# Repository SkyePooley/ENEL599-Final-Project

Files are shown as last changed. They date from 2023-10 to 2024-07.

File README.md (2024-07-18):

# Pong Game on Arduino LED Matrix
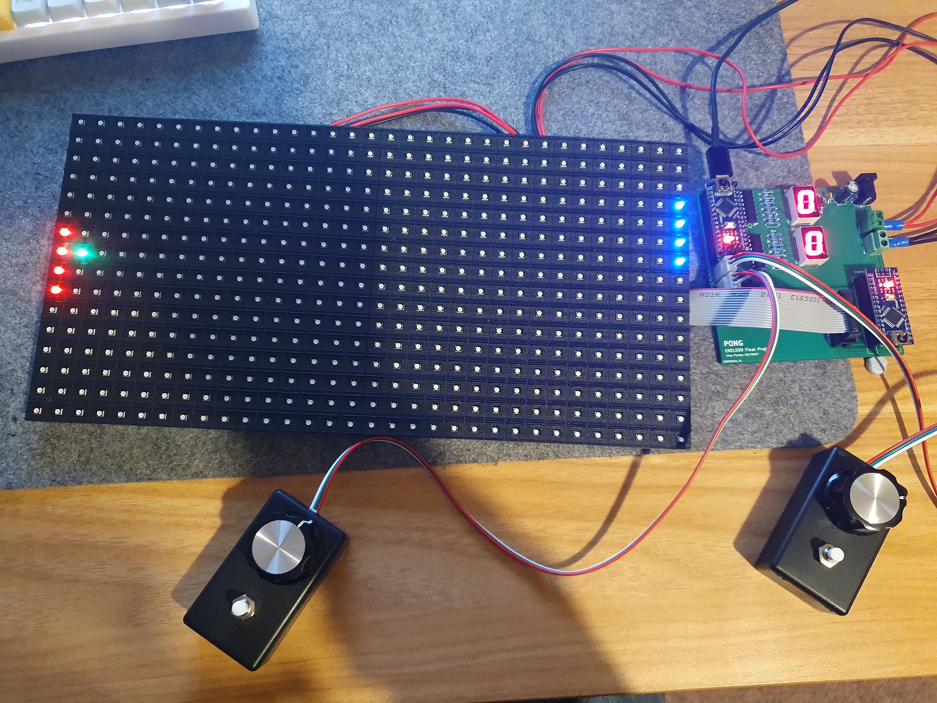
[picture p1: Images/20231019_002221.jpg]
Pong running on the game system

Recreation of Atari's *home pong* game system which plays a game of pong on a 64x32 LED matrix.  
This repository includes my schematics, PDB designs, and C++ code for the microcontrollers.
The PCB is designed for manufacturing with JLCPCB in two layers, exported files are included.

Schematic for mainboard

Due to memory constraints the functions of the system are split between two microcontrollers, one of which runs the game and IO while the other drives the display.

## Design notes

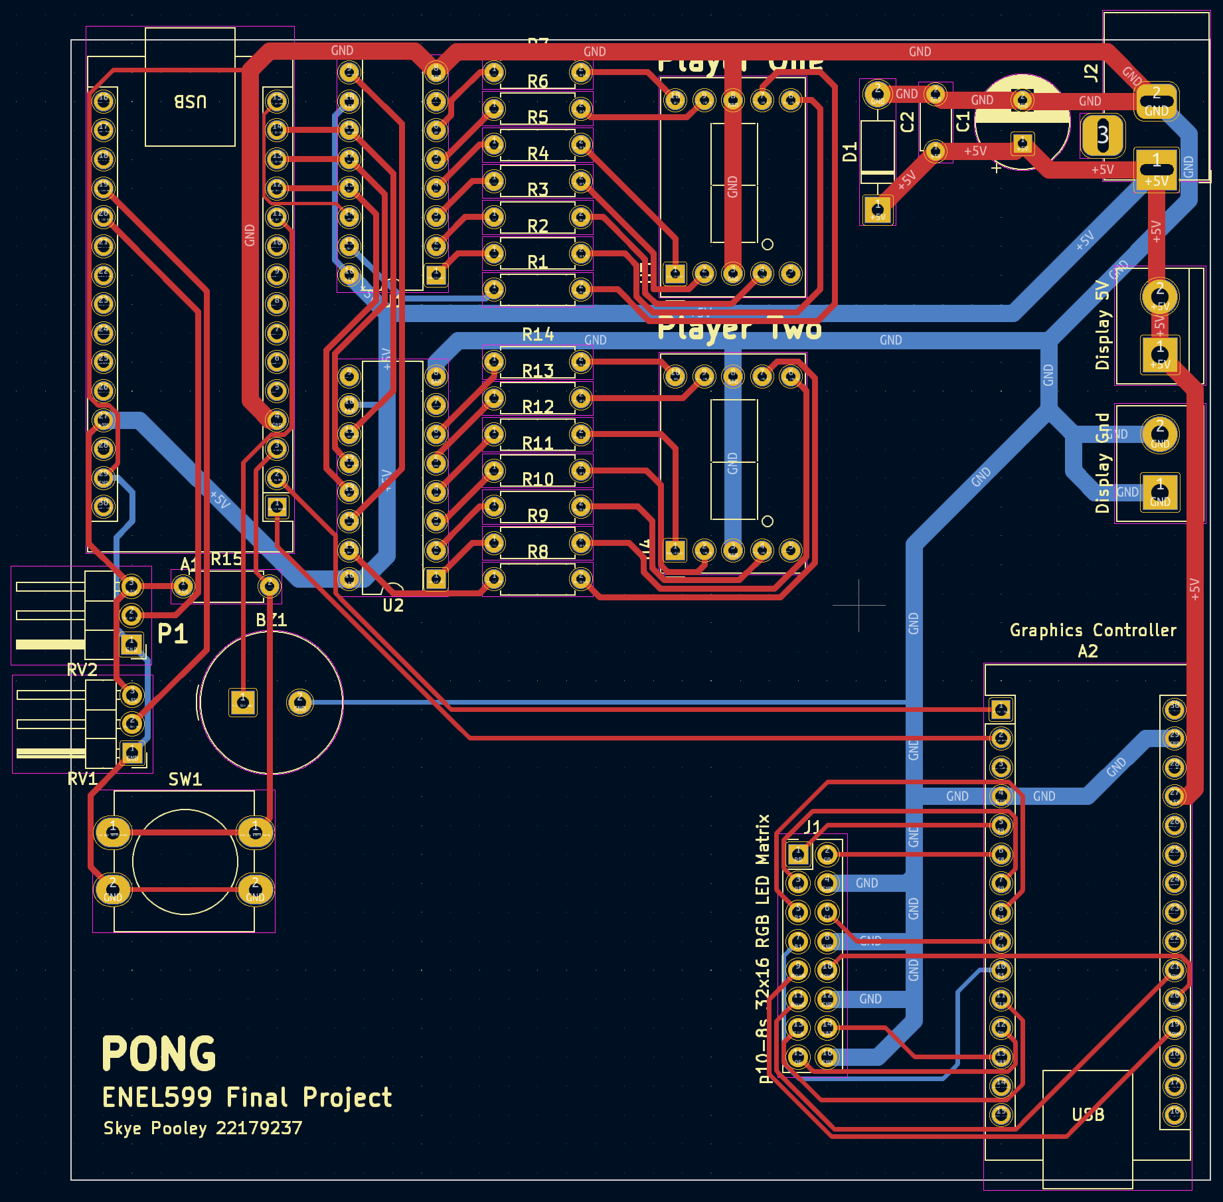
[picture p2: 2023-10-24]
PCB Layout (No zone fills).png

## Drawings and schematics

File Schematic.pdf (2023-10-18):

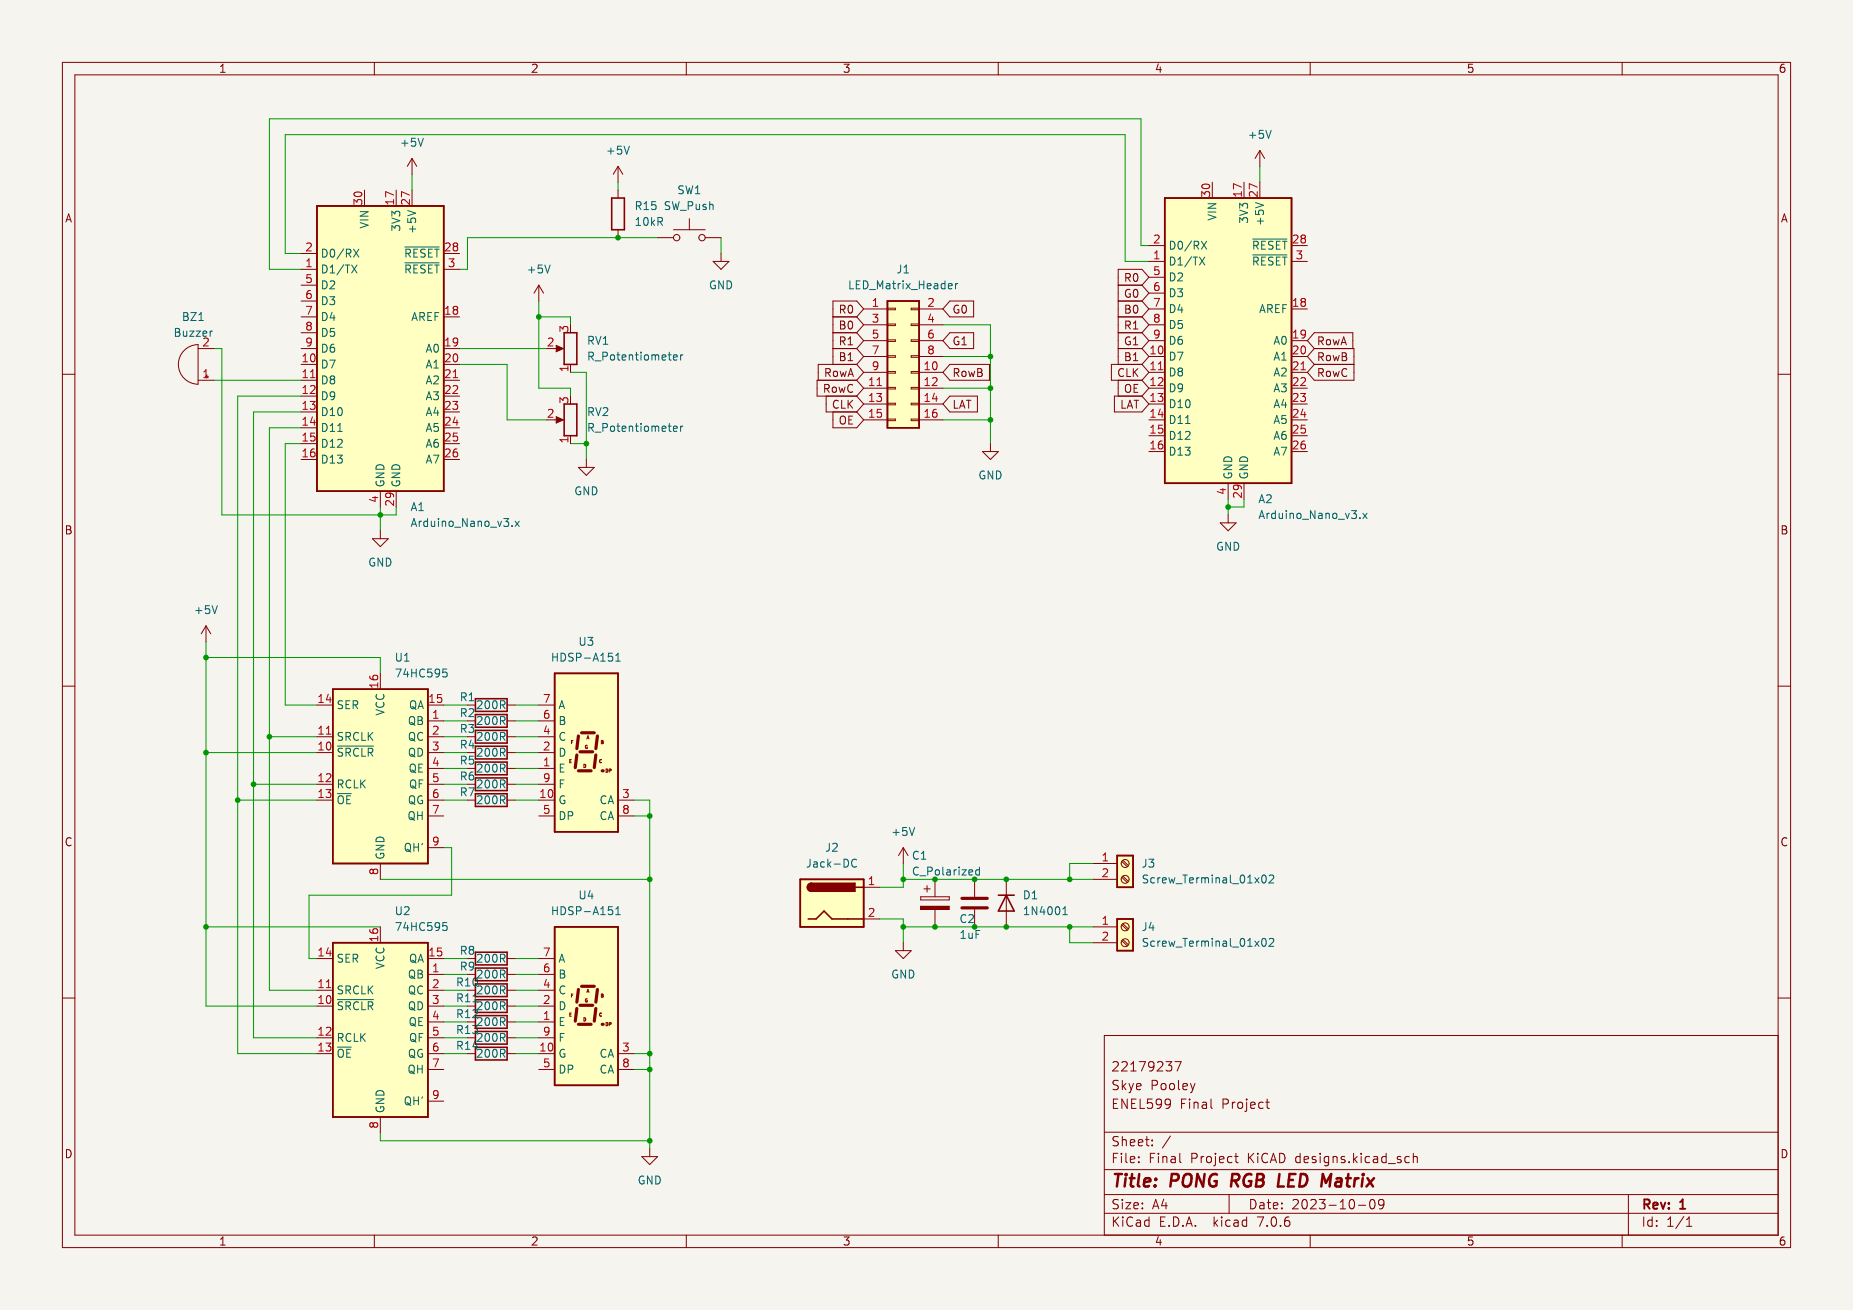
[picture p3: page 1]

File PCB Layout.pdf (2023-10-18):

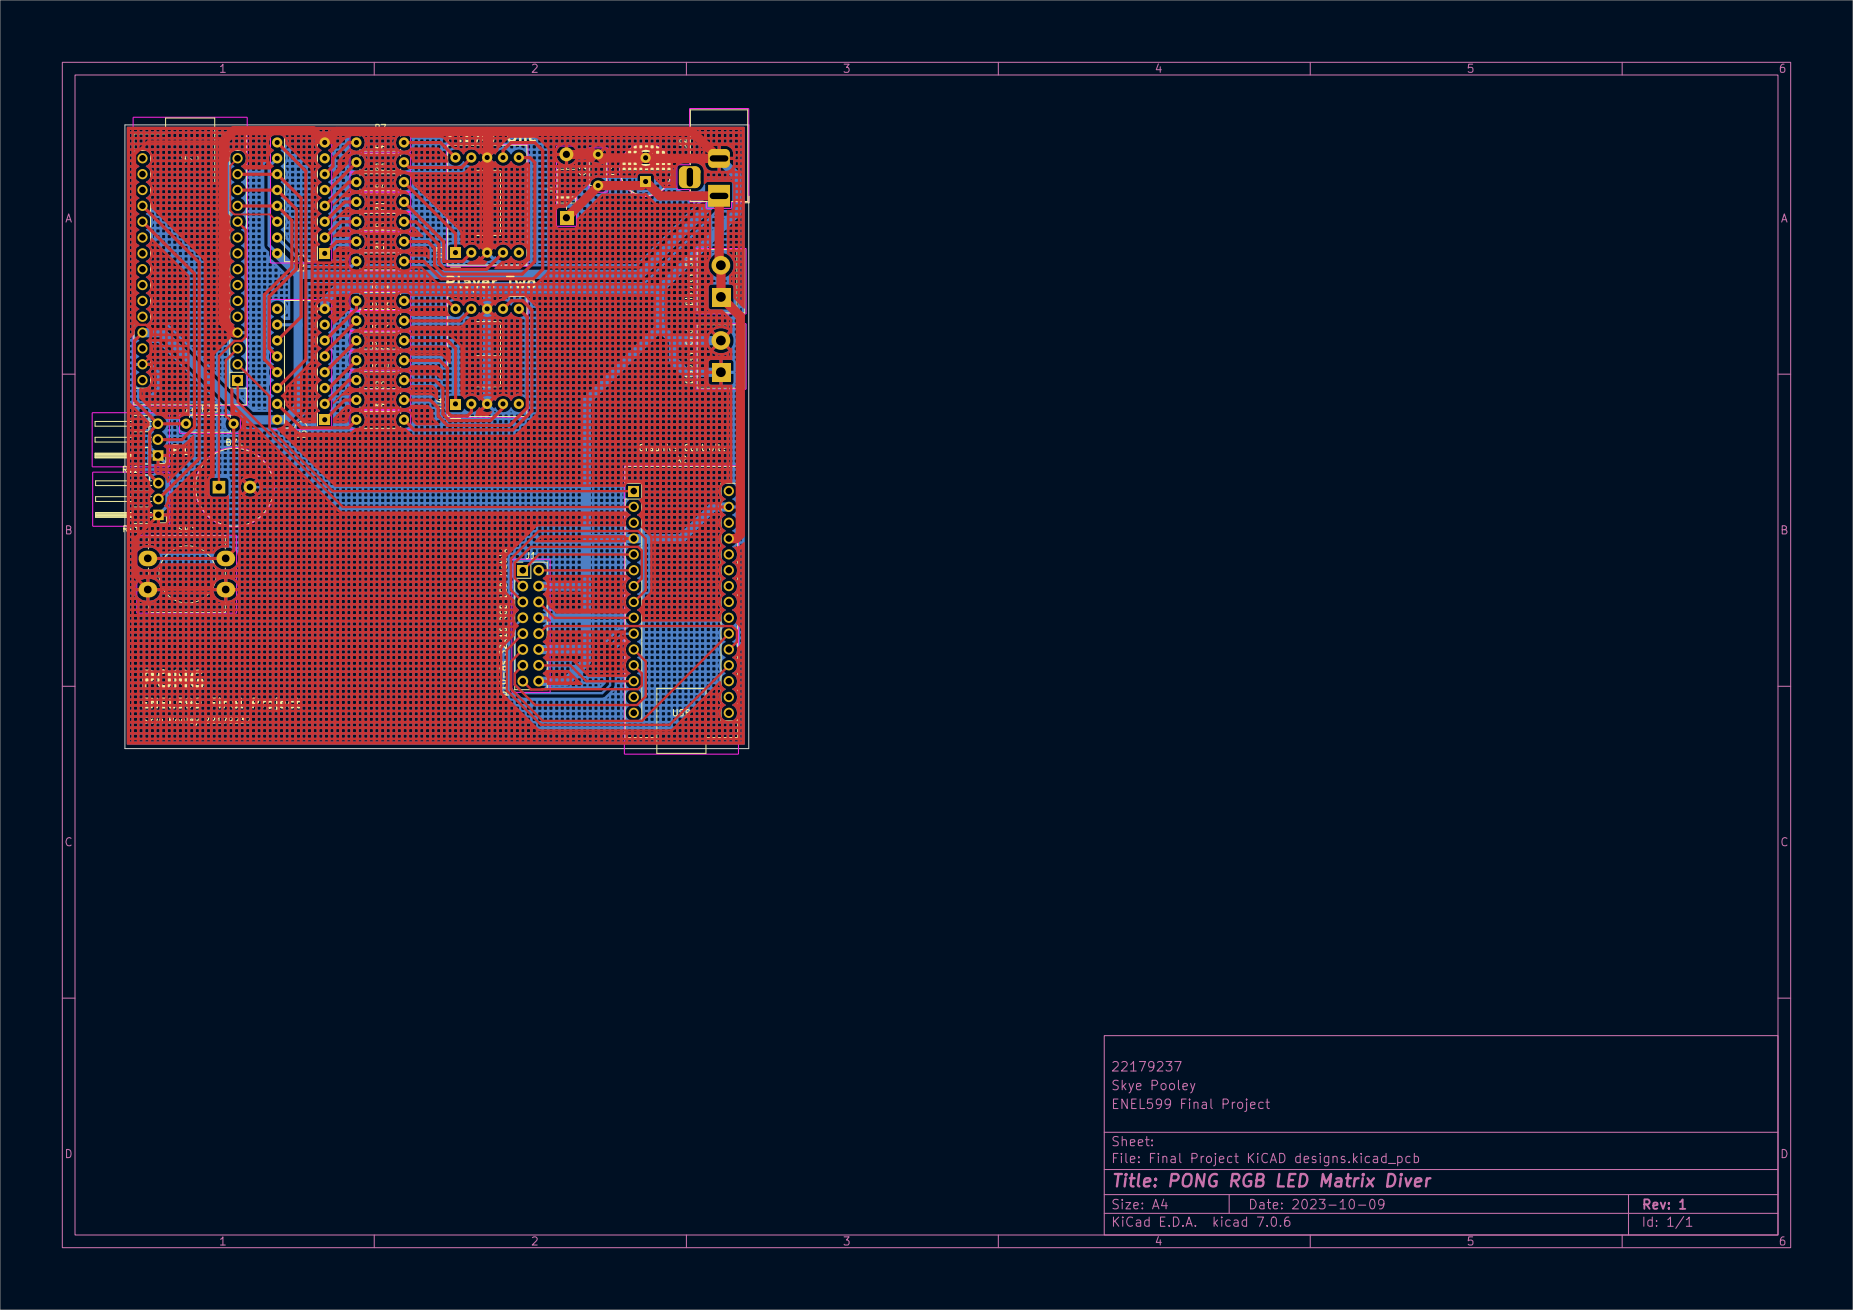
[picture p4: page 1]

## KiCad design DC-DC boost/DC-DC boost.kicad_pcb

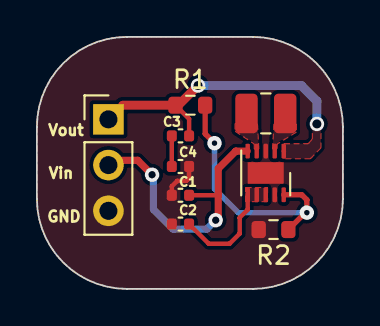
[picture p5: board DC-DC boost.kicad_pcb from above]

Board: 2 copper layers, 17.0 x 14.0 mm, 9 parts (0 on the bottom side), 8 nets.

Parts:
C1, C2, C3, C4: C; C_0402_1005Metric
FTC252012S1R5MBCA1: 1.5uH; L_1008_2520Metric
J1: Conn_01x03; PinHeader_1x03_P2.54mm_Vertical
R1: 2.8M; R_0603_1608Metric
R2: 500K; R_0603_1608Metric
U1: TPS63030DSK; WSON-10-1EP_2.5x2.5mm_P0.5mm_EP1.2x2mm

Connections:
unnamed: C3.2, C4.1
unnamed: C3.1, J1.1, R1.1, U1.1 (VOUT)
unnamed: C1.1, J1.2, U1.5 (VIN)
unnamed: C1.2, C2.2, C4.2, J1.3, R2.2, U1.3 (PGND), U1.9 (GND), U1.11 (PGND)
unnamed: C2.1, U1.6 (EN), U1.7 (PS/SYNC), U1.8 (VINA)
unnamed: R1.2, R2.1, U1.10 (FB)
unnamed: FTC252012S1R5MBCA1.1, U1.4 (L1)
unnamed: FTC252012S1R5MBCA1.2, U1.2 (L2)

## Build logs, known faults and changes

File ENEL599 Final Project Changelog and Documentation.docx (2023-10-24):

# ENEL599 Final Project

# Premise

I decided to make a pong gaming system using an LED display panel. The Arduino will output its display to a 32x16 p10-8s RGB LED panel. Player input can be gathered using two potentiometers which map their turn range to the paddle position for that player. Score should be output to two 7-segment displays. A speaker or buzzer should beep when the ball hits a panel or goes out of bounds.

### Inspiration

https://www.youtube.com/watch?v=cm83RIhDbwo

### Helpful Libraries and Guides

https://learn.adafruit.com/32x16-32x32-rgb-led-matrix/new-wiring

https://www.circuitbasics.com/programming-with-classes-and-objects-on-the-arduino/

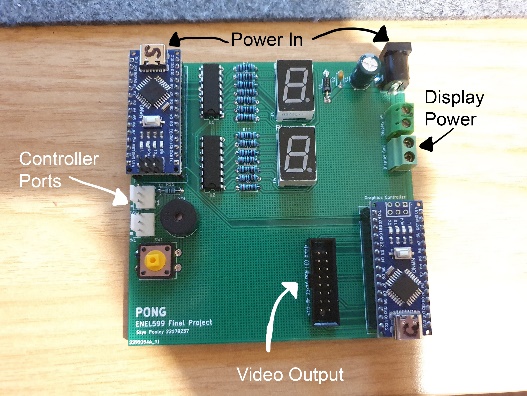
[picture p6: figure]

# Documentation

Connect the video output from the PCB to the video input of the matrix panel. Connect the screw terminal power outputs to the power input of the matrix panel. Then connect the two controllers to the ports on the left side. Then connect power to turn on the system.

Use the dials on the controllers to position each player’s “paddle”, then the player who’s turn it is to serve can press the white button on the controller to serve the ball. If a player misses the ball when it comes their way then the opposing player will be given a point. The first player to reach three points (adjustable in software) will win the game. After this, press the yellow button to play again.

## Parts list

- RGB LED Panel P10-8s
- Arduino nano for panel driving
- Second Arduino for game simulation, player IO.
- 2x 7-segment display
- Shift register 74hc595
- 5V 15W power supply.
- 2x 10kr Potentiometers with knobs

# Changelog

## Panel Driver Prototyping

After attempting to interact with the shift-registers in the display panel I decided that I would not have enough time to write my own driver code at this stage. I decided to use the Adafruit LEDMatrix library to drive the panel.

My initial prototype used a breadboard to connect the Arduino to the LED panel but encountering some instability issues I decided to move this section to a soldered prototyping board to eliminate inconsistent connections.

I ran a test to check if the line-select wires were incorrectly connected by lighting up each row of the display in order. I noticed some lines lighting up in the incorrect order so I swapped the line select pins in software, this resolves my image distortion.

## 7-Segent Display Prototyping

To display the scores, I wanted to use 7-segment displays driven by shift registers to minimize pin use on my Arduino. Using a second Arduino I wired up two displays, one for each shift register and chained the registers together.

After correcting some misplaced wires, I was able to display numbers on the displays by mapping segment on/off states to bits in a byte and shifting this byte out into the registers.

## PCB Design

To integrate my two prototypes into a cohesive system, I decided to design and order a PCB. I designed a schematic in KiCAD and then imported the nets into the KiCAD PCB designer. After making all connections and ensuring the design passed DRC I sent the files to JLCPCB for manufacturing.

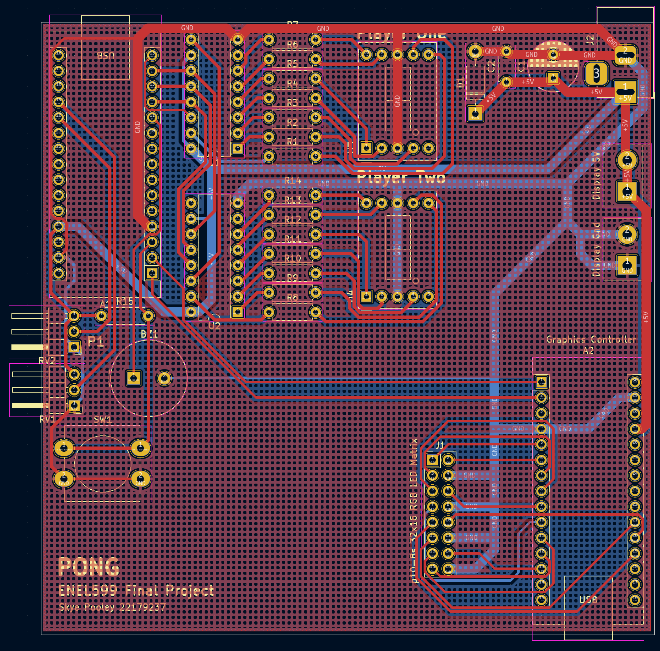
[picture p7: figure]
PCB with ground fills visible
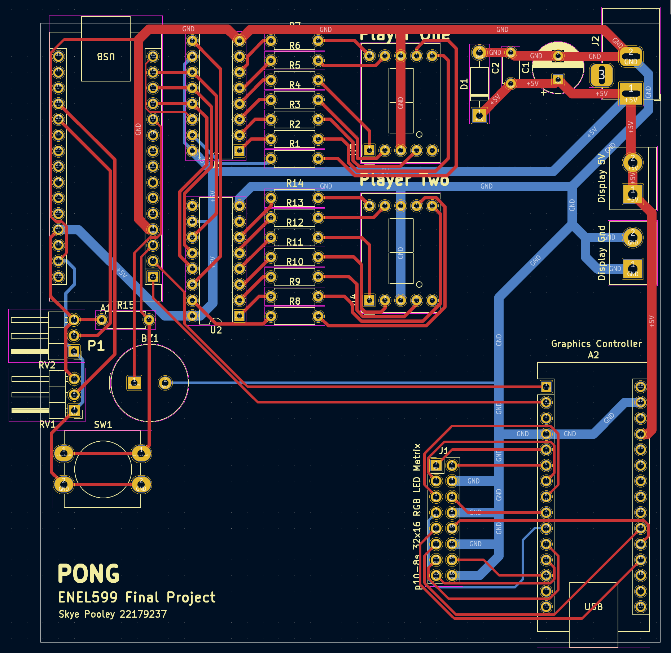
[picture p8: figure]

PCB Design shown with and without ground fills visible.

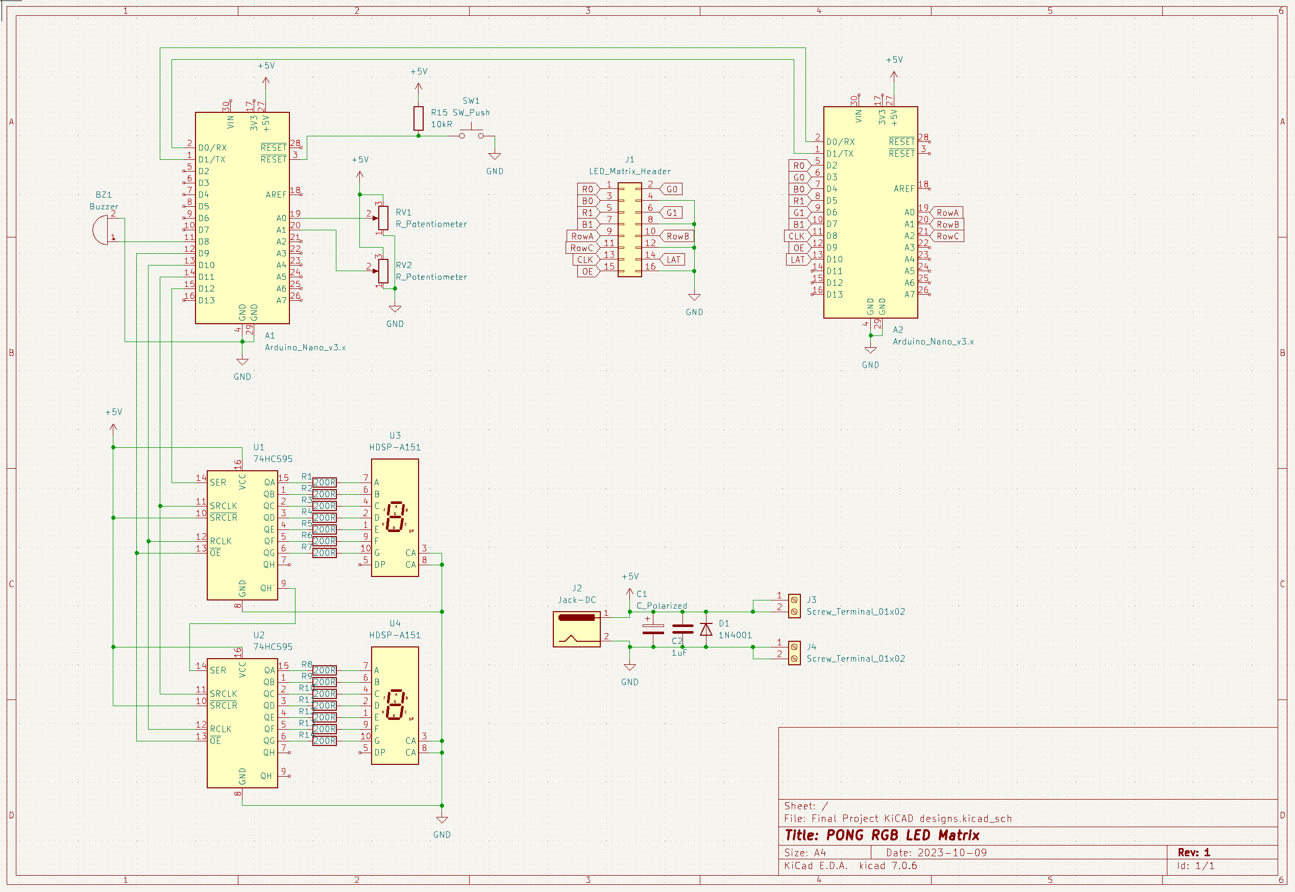
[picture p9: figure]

Schematic.

## Serial Communication

The computation for the game needs to be split between two Arduinos due to memory constraints. The PCB design connects the two Arduinos via serial so that one can handle video rendering while it receives information on entity positioning via serial from the other Arduino which handles IO and game simulation.

Numbers to transmit:

1. Paddle A position – 0-15 (4 bits)
2. Paddle B position – 0-15
3. Ball horizontal pos – 0-31 (5 bits)
4. Ball vertical pos = 0-15

We will need 5 bits to transmit the value of each number leaving three bits for the flag.

Three flag bits gives us 8 possible flags, more than currently needed.

Because this totals 8 bits we can transmit each value in a single byte rather than transmitting flags and values separately. This will simplify the serial protocol as we don’t need to worry about matching up the bytes.

Each transmitted byte is in the form 0bFFFVVVVV where F is the flag and V is the value.

## Controllers

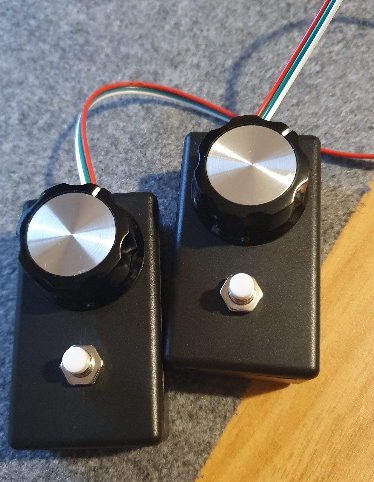
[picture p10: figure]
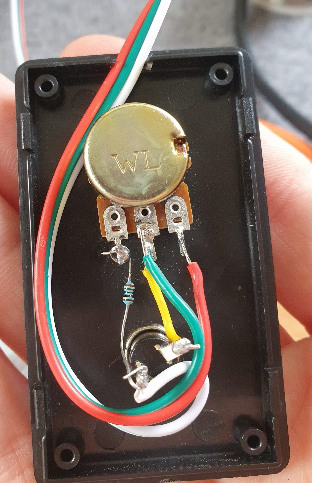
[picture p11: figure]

The player input needed a dial for paddle positioning and a button to serve the ball on a player’s turn. The cables that I had on hand were only three pin so I needed a way to transmit both the potentiometer and button input over one wire. To do this I wired the potentiometer ground through a 1k resistor to limit its output range to 0.5-5V. The button would then pull the output down to 0V.

## Fully Functional Game

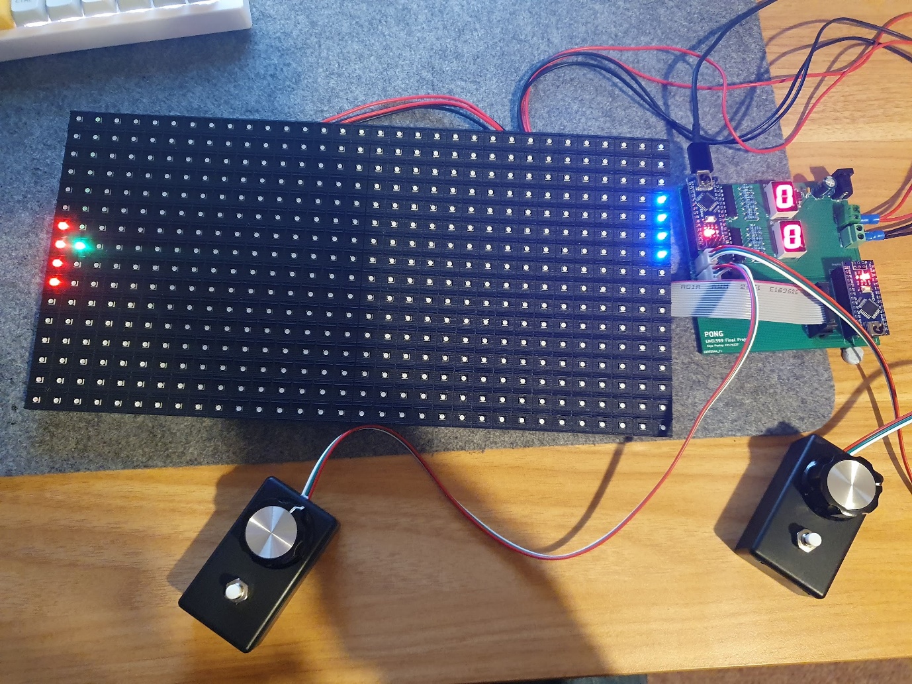
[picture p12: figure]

I used the lessons that I learned from the prototypes to write the code for the first fully integrated version.

ENEL599 Assignment 3 | Skye Pooley 22179237

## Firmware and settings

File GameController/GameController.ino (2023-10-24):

/*
    ENEL599 Final Project Game Controller code
    October 2023 - Skye Pooley - 22179237
    Plays PONG!
    This code works in tandem with the "Graphics controller code" on the other arduino.
    Both controllers are needed for the game to work.
    This controller handles:
        Input from the players
        Simulation of game objects
        Playing of sound effects and simple music
        Output to 7-segment displays to show player scores
        Transfer of game entity positions over serial to graphics controller arduino.
*/

// Labels for serial data flags, used to determine what a transmitted number refers to.
#define FLAG_PADDLE_A 0
#define FLAG_PADDLE_B 1
#define FLAG_BALL_X   2
#define FLAG_BALL_Y   3

// ------  Static variables and pin assignments ------ //
const int SER_PIN = 12;
const int SCLK_PIN = 11;
const int RCLK_PIN = 10;
const int OE_PIN = 9;
const int BUZZER = 8; // piezo
const int CONTROLLER_ONE = A0; // player input
const int CONTROLLER_TWO = A1;

// ------- Reference numbers for game function -------- //
const int FRAME_RATE = 60;
const int FRAME_TIME = 1000/FRAME_RATE; // time inbetween frames/refreshes.
const int resolution[2] = {32, 16};
const int PADDLE_WIDTH = 4; // for collision detecion
const float DEFAULT_SPEED[2] = {0.25, 0.35}; // default ball velocity
// the game input controller pins function both as button inputs and potentiometer inputs.
// When the input value is below this cutoff it should be treated as a button instead of a dial.
const int CONTROLLER_BUTTON_CUTOFF = 70;
const int WIN_SCORE = 3; // number of rounds that a player has to win in order to win the game.


// ------- Music tracks and sound effects --------
struct MusicTrack {
    unsigned int notes[100][2]; // each position in the array is one note which contains a frequency and duration.
    unsigned int length; // used to track when the song ends.
};

static struct MusicTrack STARTUP_JINGLE = {
    {
        {987, 100},
        {3951, 300}
    },
    2 // Taken from the GameBoy startup sound
};

static struct MusicTrack MISS = {
    {
        {600, 10},
        {850, 10},
        {400, 10},
        {250, 10},
        {400, 10},
        {250, 10},
        {400, 10},
        {250, 10},
        {100, 250}
    },
    11
};

static struct MusicTrack HIT = {
    {
        {600, 10},
        {850, 10},
        {600, 10},
        {850, 10},
        {600, 10},
        {950, 10},
    },
    8
};

// this one sounds terrible, I need to compose something better.
static struct MusicTrack WIN = {
    {
        {600, 10},
        {850, 10},
        {600, 10},
        {850, 10},
        {850, 10},
        {1050, 10},
        {850, 10},
        {1050, 500},
        {600, 400},
        {1050, 800}
    },
    10
};

/*
    Keeps track of the player scores and manages the 7-segment displays.
    SER_PIN:    pin which carries the serial data to the shift registers
    SCLK_PIN:   pin which carries the serial clock 
    RCLK_PIN:   pin chich carries the register clock to move data to the output registers
    OE_PIN:     pin which enables and disables the register outputs, active low.
*/
class ScoreCounter {
    private:
        // Each bit in these bytes represents one segment of a 7-segment display. 
        // The final bit is the decimal point which is not used.
        // When referencing this array, the index number corresponds to the number displayed using that byte.
        const unsigned char digitMappings[10] = {
            0b11111100, //0
            0b01100000, //1
            0b11011010, //2
            0b11110010, //3
            0b01100110, //4
            0b10110110, //5
            0b10111110, //6
            0b11100000, //7
            0b11111110, //8
            0b11100110, //9
        };
        int SER;
        int SCLK;
        int RCLK;
        int OE;
        int scores[2];
    public:
        ScoreCounter(int SER_PIN, int SCLK_PIN, int RCLK_PIN, int OE_PIN) {
            SER = SER_PIN;
            SCLK = SCLK_PIN;
            RCLK = RCLK_PIN;
            OE = OE_PIN;
            scores[0] = 0;
            scores[1] = 0;
        }

        /* Increase the first player's score unless they have already reached the winning score.
           Updates the 7-segment displays with the new value. */
        void incrementPlayerOneScore() {
            if (scores[0] < WIN_SCORE) {
                scores[0]++;
            }
            refresh(); // show new value on displays
        }

        // Increase the second player's score unless they have already reached the winning score.
        void incrementPlayerTwoScore() {
            if (scores[1] < WIN_SCORE) {
                scores[1]++;
            }
            refresh();
        }

        int getPlayerOneScore() {
            return scores[0];
        }

        int getPlayerTwoScore() {
            return scores[1];
        }

        // Clears all data in the shift registers setting all segments to off.
        void clearRegisters() {
            digitalWrite(OE, HIGH); // Disable output
            digitalWrite(RCLK, LOW);
            shiftOut(SER, SCLK, MSBFIRST, 0b00000000); 
            shiftOut(SER, SCLK, MSBFIRST, 0b00000000);
            digitalWrite(RCLK, HIGH); // shift new data to output register.
            delay(1);
            digitalWrite(RCLK, LOW);
            digitalWrite(OE, LOW); // Show output again
        }

        /* 
            Change shift register outputs to match new values.
            Maximum value of nine.
        */
        void refresh() {
            if (scores[0] <= 9 && scores[1] <= 9) {
                digitalWrite(OE, HIGH); // hide output while we are messing with it
                // shift the second players score onto the first register
                shiftOut(SER, SCLK, LSBFIRST, digitMappings[scores[0]]); 
                // shift the first player's score onto first register, moving second player score to second register.
                shiftOut(SER, SCLK, LSBFIRST, digitMappings[scores[1]]); 
                digitalWrite(RCLK, HIGH);
                digitalWrite(RCLK, LOW);
                digitalWrite(OE, LOW); // show new values
            }
        }
        /*
            Set the counters back to zero.
        */
        void reset() {
            clearRegisters();
            scores[0] = 0;
            scores[1] = 0;
            refresh();
        }
};

/*
    Manages the playback of sounds
    Call update each loop to keep things on time
*/
class SoundManager {
    private:
        unsigned long toneEndTime; // records the time when a started tone should be stopped.
        bool soundPlaying;
        struct MusicTrack* p_activeTrack; // currently playing music track
        int trackIndex; // what note in the track are we up to
        int BUZZER; // pin for piezo buzzer

        // Play a singel note on the buzzer with a set duration
        void startTone(unsigned int frequency, unsigned int duration) {
            tone(BUZZER, frequency);
            toneEndTime = millis() + duration;
        }
    public:
        SoundManager(int BUZZER_PIN) {
            BUZZER = BUZZER_PIN;
            soundPlaying = false;
            toneEndTime = 0;
            trackIndex = 0;
        }

        // Begin playback of a track, updates variables and starts the first note.
        void beginSound(struct MusicTrack* p_newTrack) {
            p_activeTrack = p_newTrack;
            soundPlaying = true;
            trackIndex = 0;
            startTone(p_activeTrack->notes[trackIndex][0], p_activeTrack->notes[trackIndex][1]); // start the first note of the new track.
        }

        // Call this every cycle to update which note is playing
        void update() {
            if (soundPlaying) {
                // check if a note should have stopped by now
                if (millis() > toneEndTime) {
                    noTone(BUZZER); 
                    trackIndex++;// move to the next note
                    // are we at the end of the track?
                    if (trackIndex == p_activeTrack->length) {
                        soundPlaying = false;
                    }
                    else {
                        startTone(p_activeTrack->notes[trackIndex][0], p_activeTrack->notes[trackIndex][1]);
                    }
                }
            }
        }        
};

// ------  Dynamic Variables  -------- //
ScoreCounter scoreCounters(SER_PIN, SCLK_PIN, RCLK_PIN, OE_PIN);
SoundManager soundManager(BUZZER);

unsigned long lastRefreshTime = 0; // time that the frame was last refreshed.
bool gameActive = false; // determines whether the ball is moving, game needs to pause inbetween turns
int playerToServe = 1; // player to serve the ball this turn
bool gameWon = false;

// Entities
unsigned int paddleOnePos = 0;
unsigned int paddleTwoPos = 0;
float ballPos[2] = {1.0, 0.0};
float ballVelocity[2] = {DEFAULT_SPEED[0], DEFAULT_SPEED[1]}; // amount to move in X,Y each refresh

// Pin Readings
int controllerOneSignal = 0;
int controllerTwoSignal = 0;

// -------- Function Prototypes -------
void sendWithID(int value5, int id3);
int updateBall(float* ballVelocity, float* ballPos, int paddleOnePos);

void setup() {
    pinMode(CONTROLLER_ONE, INPUT);
    pinMode(CONTROLLER_TWO, INPUT);
    pinMode(BUZZER, OUTPUT);
    pinMode(SER_PIN, OUTPUT);
    pinMode(RCLK_PIN, OUTPUT);
    pinMode(SCLK_PIN, OUTPUT);
    pinMode(OE_PIN, OUTPUT);

    scoreCounters.refresh();
    soundManager.beginSound(&STARTUP_JINGLE);
    Serial.begin(115200);
}

void loop() {
    // ----- Handle Inputs ----- //
    controllerOneSignal = analogRead(CONTROLLER_ONE);
    controllerTwoSignal = analogRead(CONTROLLER_TWO);
    // if the controller signal is being used for the dial and not the button
    if (controllerOneSignal > CONTROLLER_BUTTON_CUTOFF)
        paddleOnePos = map(controllerOneSignal, CONTROLLER_BUTTON_CUTOFF,1023, 0,13); // map to screen space
    if (controllerTwoSignal > CONTROLLER_BUTTON_CUTOFF)
        paddleTwoPos = map(controllerTwoSignal, CONTROLLER_BUTTON_CUTOFF,1023, 0,13);

    soundManager.update(); // sounds have to be updated more frequently than the refresh timer as some notes may be very short.
  
    // ----- Update Game on time ----- //
    if (millis() > lastRefreshTime + FRAME_TIME) {
        // If there is a current round happening
        if (gameActive) {
            // Update the ball position and handle point conditions.
            switch (updateBall(ballVelocity, ballPos, paddleOnePos)) {
                case 1:
                    soundManager.beginSound(&MISS);
                    scoreCounters.incrementPlayerOneScore();
                    gameActive = false;
                    playerToServe = 1;
                    break;
                case 2:
                    soundManager.beginSound(&MISS);
                    scoreCounters.incrementPlayerTwoScore();
                    gameActive = false;
                    playerToServe = 2;
                    break;
            }
        }
        // Game is between rounds but the game is not yet won
        else if (!gameWon) {
            switch (playerToServe) {
                case 1:
                    ballPos[1] = paddleOnePos + 1;
                    if (controllerOneSignal < 10) { gameActive = true; }
                    break;
                case 2:
                    ballPos[1] = paddleTwoPos + 1;
                    if (controllerTwoSignal < 10) { gameActive = true; }
                    break;
            }
        }

        // Check if either player has reached the win condition and the game has not yet been won.
        if ((scoreCounters.getPlayerOneScore() >= WIN_SCORE || scoreCounters.getPlayerTwoScore() >= WIN_SCORE) && !gameWon) {
            // Congratulations!
            gameWon = true;
            soundManager.beginSound(&WIN);
        }

        // send entity positions to graphics controller
        sendWithID(paddleOnePos, FLAG_PADDLE_A);
        sendWithID(paddleTwoPos, FLAG_PADDLE_B);
        sendWithID((int)ballPos[0], FLAG_BALL_X);
        sendWithID((int)ballPos[1], FLAG_BALL_Y);

        lastRefreshTime = millis();
    }
}


// -------- Helper Functions --------

/* 
Sends a value over serial with an identifying flag.
value5: value of the transmitted number, max 5 bit precision.
id3:    id flag of the number being send, max 3 bit precision.
*/
void sendWithID(int value5, int id3) {
    // shift the id flag to the three most significant bits, then join with the value.
    Serial.write((id3 << 5) ^ value5);
}

/*
    Calculates the new position of the ball and checks for collisions with screen edges and paddles.
    returns 0 if the game continues,
    returns 1 if player one got a point and the game needs to pause,
    returns 2 if player two got a point and the game needs to pause.
*/
int updateBall(float* ballVelocity, float* ballPos) {
    // Update the ball's position according to the velocity vector
    ballPos[0] += ballVelocity[0];
    ballPos[1] += ballVelocity[1];

    // Reflect off the top and bottom of the screen
    if (ballPos[1] < 0 || ballPos[1] > 15) {
        ballVelocity[1] *= -1;
    }

    // Has the ball reached the left side of the screen?
    if (ballPos[0] < 1) {
        // Is the first player's paddle in position to hit the ball?
        if ((int)ballPos[1] >= paddleOnePos && paddleOnePos+PADDLE_WIDTH >= (int)ballPos[1]) {
            // Yes! reflect back the other direction 
            ballVelocity[0] *= -1;
            soundManager.beginSound(&HIT);
        }
        else {
            // No :( pass the ball to the other player
            ballPos[0] = 30;
            ballVelocity[0] = DEFAULT_SPEED[0] * -1;
            ballVelocity[1] = DEFAULT_SPEED[1];
            return 2; // tell the parent function that player 2 needs a point
        }
    }
    // Has the ball reached the right side of the screen?
    else if (ballPos[0] > 31) {
        // Is player two's paddle in position to hit the ball?
        if ((int)ballPos[1] >= paddleTwoPos && paddleTwoPos+PADDLE_WIDTH >= (int)ballPos[1]) {
            // Yes! reflect
            ballVelocity[0] *= -1;
            soundManager.beginSound(&HIT);
        }
        else {
            // No :( pass the ball to the other player
            ballPos[0] = 1;
            ballVelocity[0] = DEFAULT_SPEED[0];
            ballVelocity[1] = DEFAULT_SPEED[1] * -1;
            return 1; // tell the parent class that player one needs a point
        }
    }
    return 0; // tell the parent class that no points need to be awarded
}

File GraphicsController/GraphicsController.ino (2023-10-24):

/*
    ENEL599 Final Project Graphics Controller
    October 2023 - Skye Pooley - 22179237
    Companion to the "Game Controller" code on the other arduino.
    This code controls the RGB LED Matrix panel for the PONG project.
    The Adafruit RGBmatrixPanel library is used for shifting out data to the panel registers
    and selecting lines.
    https://github.com/adafruit/RGB-matrix-Panel
    Receives the position of entities to draw over serial.
*/

#include <RGBmatrixPanel.h>

// Control pins for the RGB panel
static int CLK = 8;
static int OE  = 9;
static int LAT = 10;
static int A   = A0;
static int B   = A1;
static int C   = A2;

// Flags for identifying incoming serial transmissions.
#define FLAG_PADDLE_A 0
#define FLAG_PADDLE_B 1
#define FLAG_BALL_X   2
#define FLAG_BALL_Y   3

static int targetRefreshRate = 60; // Rate to refresh the display at in Hz.
static int frameTime = 1000 / targetRefreshRate;
static int paddleDimensions[2] = {1,4}; // x,y

RGBmatrixPanel matrix(A, B, C, CLK, LAT, OE, false);

// Timer to update the video output at a regular rate
unsigned long lastDrawnTime = millis();

// Vertical position of the paddles
int paddleOnePos = 0;
int paddleTwoPos = 0;

// 0-31, 0-15 matched to matrix dimensions. Origin 0,0 is top left.
int ballPosition[2] = {0, 7}; 


void drawFrame(){
    matrix.fillScreen(matrix.Color333(0, 0, 0));// clear display
    // Draw paddles
    matrix.fillRect(0, paddleOnePos, paddleDimensions[0], paddleDimensions[1], matrix.Color333(7, 0, 0));  // Player One
    matrix.fillRect(31, paddleTwoPos, paddleDimensions[0], paddleDimensions[1], matrix.Color333(0, 0, 7)); // Player Two
    matrix.drawPixel(ballPosition[0], ballPosition[1], matrix.Color333(0, 7, 0)); // Ball
}

void setup() {
  pinMode(OE, OUTPUT);
  pinMode(LAT, OUTPUT);
  pinMode(A, OUTPUT);
  pinMode(B, OUTPUT);
  pinMode(C, OUTPUT);
  pinMode(CLK, OUTPUT);

  matrix.begin();
  matrix.fillScreen(matrix.Color333(0, 0, 0));
  Serial.begin(115200);
}

void loop() {
    // Receive data from control arduino
    while(Serial.available() > 0) {
        char receivedByte = Serial.read();
        char flag = (receivedByte & 0b11100000) >> 5;
        char value = receivedByte & 0b00011111;

        // Match flag to variable
        switch(flag) {
          case FLAG_PADDLE_A:
            paddleOnePos = value;
            break;
          case FLAG_PADDLE_B:
            paddleTwoPos = value;
            break;
          case FLAG_BALL_X:
            ballPosition[0] = value;
            break;
          case FLAG_BALL_Y:
            ballPosition[1] = value;
            break;
        }
    }
  
    // Refresh the video output on time.
    if (millis() - lastDrawnTime > frameTime) {
        lastDrawnTime = millis();
        drawFrame();
    }
}

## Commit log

2023-10-03 Initial Commit
    At this stage I have learned how to drive the panel using the Adafruit RGBMatrix library. The code draws a moving square on a black canvas.
2023-10-06 7-segment display prototype
    Wrote code to count from 0-9 on 7-segment displays driven by shift registers. Also began designing schematic.
    [Final Project KiCAD designs.kicad_pcb, Final Project KiCAD designs.kicad_sch]
2023-10-15 PCB Designs and Sound
    [Final Project KiCAD designs-B_Cu.gbr, Final Project KiCAD designs-B_Mask.gbr, Final Project KiCAD designs-B_Paste.gbr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]
2023-10-16 One player prototype
2023-10-18 Tidy up and commenting
    [Final Project KiCAD designs.kicad_sch]
2023-10-19 Reworked sound system
    Sound management is now class based
    [GameController.ino]
